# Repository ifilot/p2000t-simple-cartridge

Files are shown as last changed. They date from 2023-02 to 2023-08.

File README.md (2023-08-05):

# P2000T Simple Cartridge




## Purpose

This repository contains a simple example on how to build your own cartridge
for the P2000T.

For more information, see [this blog post](https://www.philips-p2000t.nl/cartridges/basic-cartridge).

## Contents

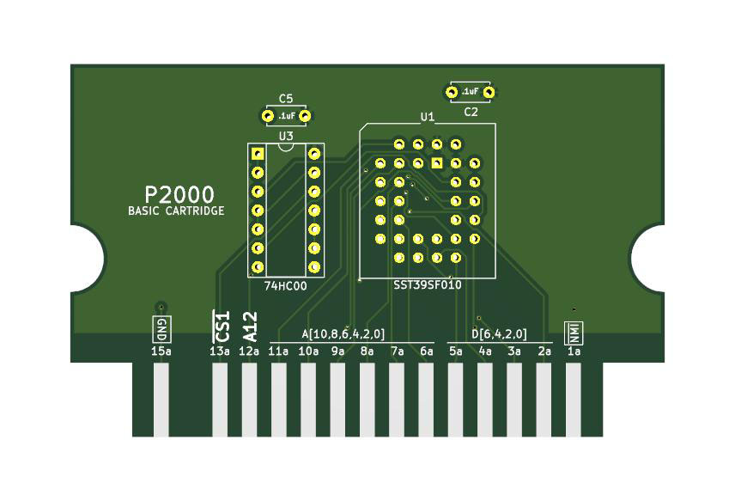
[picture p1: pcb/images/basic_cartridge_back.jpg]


* [KiCad source files](pcb/basic_cartridge) for the PCB.
* [STL files]((case)) for a cartridge enclosure.
* [Simple Hello World program](assembly/hello_world/hello_world.asm) source code for the ROM.

## Cartridge BOM

* [74HC00 Quad NAND gate](https://www.reichelt.nl/nl/nl/4-voudige-2-input-nand-poorten-2--6-v-dil-14-74hc-00-p3119.html?r=1)
* [SST39SF010 rom chip](https://www.reichelt.nl/nl/nl/multi-nor-flash-geheugen-1-mb-128-k-x-8-5-v-plcc-32-39sf01070-4c-n-p266390.html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)
* [PLCC32 IC-socket](https://www.reichelt.nl/nl/nl/ic-fitting-32-polig-plcc-plcc-32-p14700.html?r=1)
* 2x 0.1 uF capacitor

## Building the software

Compile the assembly file via:

```bash
cd assembly
make
```

and flash the resulting `hello_world.bin` file to the EEPROM. 

See also [this repository](https://github.com/ifilot/pico-sst39sf0x0-programmer) 
for a cheap PICO-based SST39SF0x0 flasher.

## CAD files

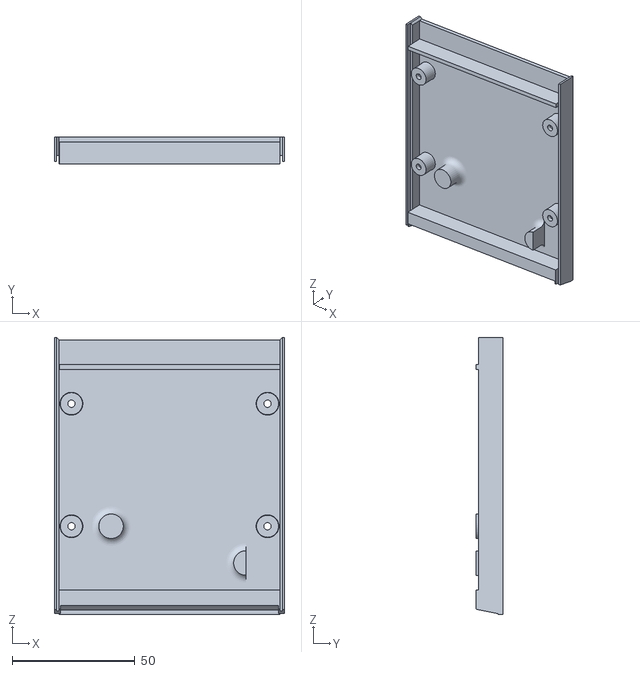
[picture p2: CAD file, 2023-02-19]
case/p2000t_basic_cartridge_bottom.stl
94.0 x 11.0 x 113.0

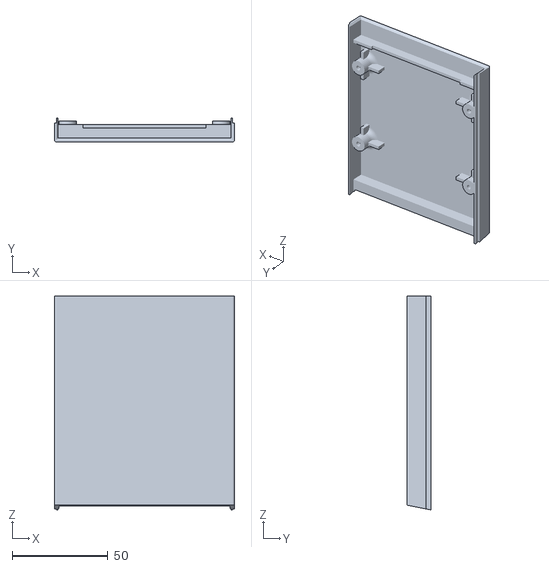
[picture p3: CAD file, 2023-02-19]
case/p2000t_basic_cartridge_top.stl
94.0 x 12.5 x 111.6

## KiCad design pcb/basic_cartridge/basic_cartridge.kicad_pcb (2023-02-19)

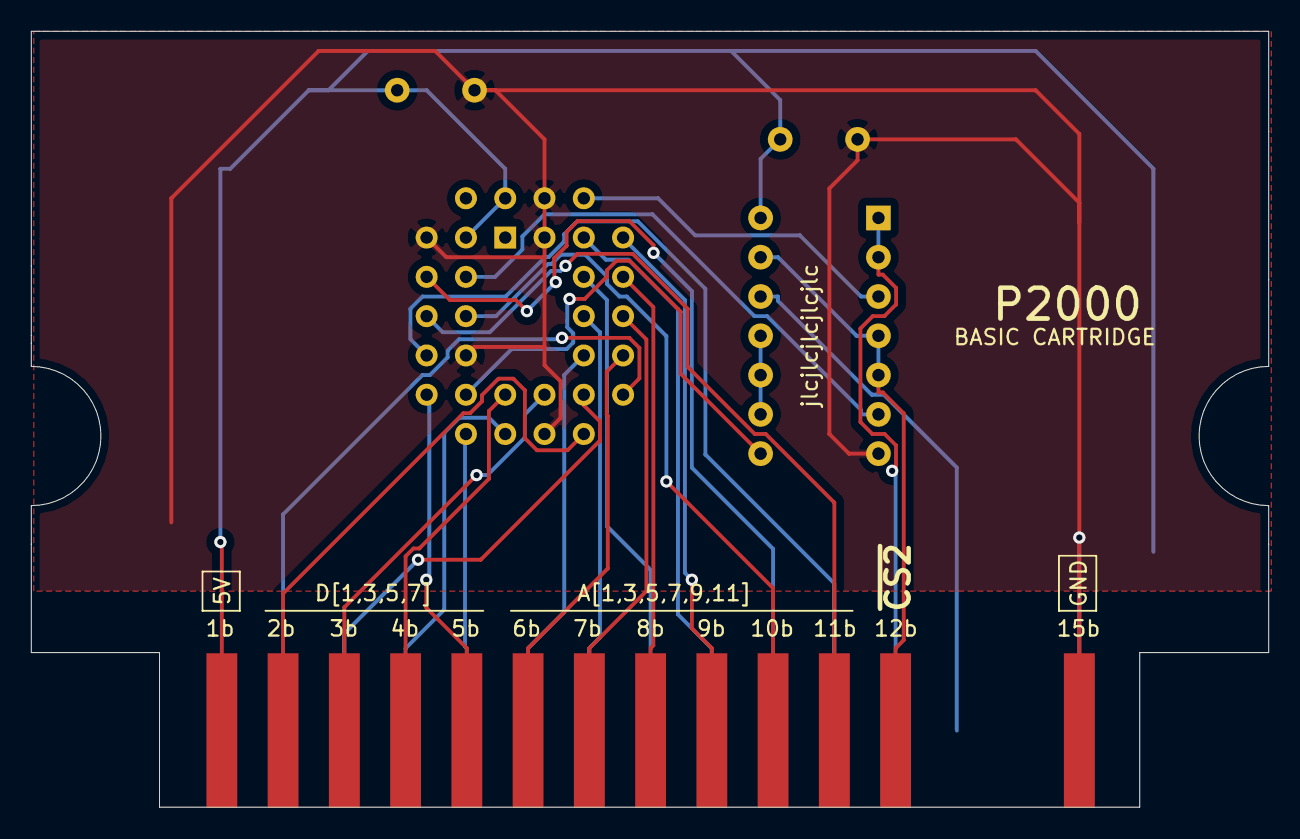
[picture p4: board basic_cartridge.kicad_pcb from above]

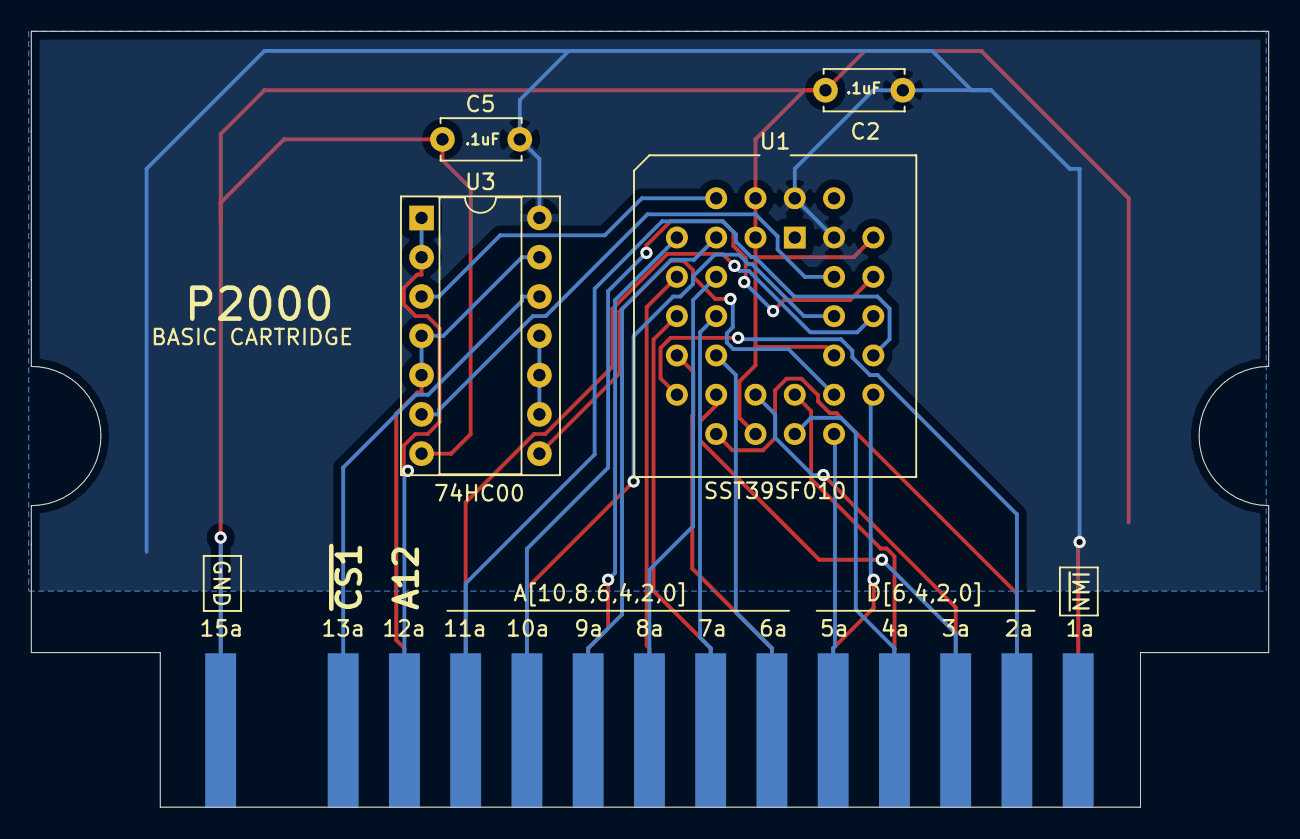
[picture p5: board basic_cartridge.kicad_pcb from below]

Board: 2 copper layers, 80.0 x 50.2 mm, 5 parts (5 on the bottom side), 29 nets.

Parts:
C2, C5: .1uF; C_Disc_D5.0mm_W2.5mm_P5.00mm
J1: P2000T_cartridge_edge; p2000t_cartridge_edge
U1: SST39SF010; PLCC-32_THT-Socket
U3: 74HC00; DIP-14_W7.62mm_Socket

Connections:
+5V: C2.1, C5.1, J1.1b, U1.31 (PGM), U1.32 (VCC), U3.14 (VCC)
A0: J1.6a, U1.12 (A0)
A1: J1.6b, U1.11 (A1)
A2: J1.7a, U1.10 (A2)
A3: J1.7b, U1.9 (A3)
A4: J1.8a, U1.8 (A4)
A5: J1.8b, U1.7 (A5)
A6: J1.9a, U1.6 (A6)
A7: J1.9b, U1.5 (A7)
A8: J1.10a, U1.27 (A8)
A9: J1.10b, U1.26 (A9)
A10: J1.11a, U1.23 (A10)
A11: J1.11b, U1.25 (A11)
A12: U1.4 (A12), U3.3
A12C: J1.12a, U3.1, U3.2
A13: U1.28 (A13), U3.6
D0: J1.2a, U1.13 (D0)
D1: J1.2b, U1.14 (D1)
D2: J1.3a, U1.15 (D2)
D3: J1.3b, U1.17 (D3)
D4: J1.4a, U1.18 (D4)
D5: J1.4b, U1.19 (D5)
D6: J1.5a, U1.20 (D6)
D7: J1.5b, U1.21 (D7)
GND: C2.2, C5.2, J1.15a, J1.15b, U1.2 (A16), U1.3 (A15), U1.16 (GND), U1.24 (OE), U1.29 (A14), U3.7 (GND)
unnamed: U3.9, U3.10, U3.11
~CARSEL1: J1.13a, U3.12
~CARSEL2: J1.12b, U3.4, U3.5, U3.13
~CS: U1.22 (CE), U3.8

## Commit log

2023-02-19 Initial commit of basic cartridge
    [basic_cartridge.kicad_pcb, basic_cartridge.kicad_sch, basic_cartridge.sch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]
2023-02-20 Adding cartridge reader
    [cartridge_reader.kicad_pcb, cartridge_reader.kicad_sch, cartridge_reader.sch]
2023-02-20 Making small adjustments to lay-out
    [cartridge_reader.kicad_pcb, cartridge_reader.kicad_sch]
2023-08-05 Refactoring repository
    [basic_cartridge.kicad_pcb, basic_cartridge.kicad_sch, basic_cartridge.sch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]

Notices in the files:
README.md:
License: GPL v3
